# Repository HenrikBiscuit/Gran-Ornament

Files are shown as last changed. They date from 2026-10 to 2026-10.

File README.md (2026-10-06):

# Gran Ornament

A small, rechargeable, two-sided LED Christmas ornament. Twenty warm-white LEDs in seven channels (three rows per side and a shared star) play slow and calm light: steady high or low, a slow breath, or a flickering candle. One button turns it on, it fades in and out, switches itself off after four hours, and sleeps quietly between Christmases.

Made by hand in small batches in Denmark. This repository is the open build log: hardware, firmware, and the notes behind the decisions.

> **Status:** 🛠 Prototyping. First batch of Rev 1 boards ordered. Firmware runs on a dev board: four light modes, button, Standby, auto-off, battery compensation and low-battery cutoff. Nothing here is production-ready yet.

<!-- Add a photo here once you have one: ![Prototype](docs/images/prototype-v0.1.jpg) -->

## Using it

| Do this | What happens |
|---|---|
| Press the button | It fades in, in the mode it had last time (high if the battery has been disconnected) |
| Short press | Next mode: high → low → breathe → candle |
| Hold for 1.5 s | It fades out and switches off |
| Leave it on | It fades out and switches off by itself after 4 hours |
| Battery runs low | It fades out, pulses softly three times ("charge me") and switches off |
| Charge | USB-C |

The brightness stays the same while the battery drains, down to the 3.6 V cutoff.

## What's in here

| Folder | Contents |
|---|---|
| [`hardware/`](hardware/) | KiCad project, datasheet links, fabrication outputs (Gerbers, BOM, CPL). Each ordered revision is a [Release](../../releases), e.g. [`hw-v1`](../../releases/tag/hw-v1) |
| [`firmware/`](firmware/) | STM32G030 firmware. Runs on the dev board for now. How to build, test and lint: [`firmware/README.md`](firmware/README.md) |
| [`firmware/tests/`](firmware/tests/) | Host-side GoogleTest tests for the firmware logic, run in CI and by the pre-push gate |
| [`docs/`](docs/) | Design decisions, power budget, pinout, bring-up notes, images |
| `production/` | Programming and test process for each batch (not created yet) |
| [`CHANGELOG.md`](CHANGELOG.md) | What changed, per hardware and firmware version |

## Key parts (current choices)

| Function | Part | Notes |
|---|---|---|
| MCU | STM32G030F6P6 | Cortex-M0+, 64 MHz, 32 KB flash, 8 KB RAM, TSSOP-20 |
| LEDs | 20 × XL-1608WWC-06 | Warm white, 1608 metric (0603 imperial) |
| Charger | MCP73831 (SOT-23-5) | Linear single-cell Li-ion/LiPo charger, 4.20 V variant, 100 mA, USB-C input |
| Protection | DW01A + FS8205A | Over-discharge, over-charge and over-current protection on the board |
| Regulator | TPS7A0233 | 3.3 V LDO, ~25 nA quiescent current |
| Button | Alps SKRTLAE010 | Side-push SMD tact switch |
| Battery | Single-cell LiPo, 250 mAh planned | Cell size *TBD* (DD-002) |

Full design rationale: [`docs/design-decisions.md`](docs/design-decisions.md)

## Design goals

1. **Works next Christmas.** Every choice favours longevity: deep sleep, over-discharge protection, a battery that survives 11 months in a box.
2. **Calm light.** Gamma-corrected, high-resolution, flicker-free PWM. Nothing jumpy, nothing "disco".
3. **Safe to hang where children and pets are.** LiPo safety and robustness are requirements.
4. **Buildable by one or two people** in batches of about 150.

## Roadmap

- [x] Initial KiCad schematic
- [x] Dev board bring-up: PWM on all 7 channels, button, Standby and wake
- [x] Light modes: high, low, breathe, candle
- [x] Battery measurement, brightness compensation and low-battery cutoff (DD-011)
- [x] Fade in and out when switching on and off
- [x] PCB layout and fabrication files (Rev 1)
- [x] First batch of Rev 1 boards ordered
- [ ] Measure Standby current on the dev board
- [ ] Gamma-corrected brightness (smooth fades at the dim end)
- [ ] Stay off when a battery is first connected (saves ~100 mAh, see the power budget)
- [ ] VDD via VREFINT (battery reading stays accurate below ~3.4 V)
- [ ] First prototype boards (Rev 1) built and brought up
- [ ] Power budget measured against calculated
- [ ] Production test jig
- [ ] Compliance groundwork (CE, GPSR, Battery Regulation)

Open tasks are tracked in [Issues](../../issues).

## Licence

Gran Ornament is **source-available for non-commercial use**. You're welcome to build one for yourself, as a gift, or with a school or makerspace, and to share improvements.

**Selling it requires permission.** That covers selling assembled ornaments, kits, or boards made from these files. Get in touch at *henrik@smitt.dk* and we'll work something out.

| What | Licence |
|---|---|
| Hardware (`hardware/`), documentation and images (`docs/`) | [CC BY-NC-SA 4.0](LICENSE-CC-BY-NC-SA) |
| Firmware (`firmware/`) | [PolyForm Noncommercial 1.0.0](LICENSE) |

The name "Gran Ornament" and any logo are not covered by these licences. Please don't use them for your own builds.

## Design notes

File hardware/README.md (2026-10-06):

# Hardware

## Layout

| Path | What goes here |
|---|---|
| `kicad/` | The KiCad project (`.kicad_pro`, `.kicad_sch`, `.kicad_pcb`) plus project-local symbol and footprint libraries |
| `kicad/lib/` | Custom symbols (`.kicad_sym`) and footprints (`.pretty/`) used by this project only |
| `fabrication/<rev>/` | Exported Gerbers, drill files, BOM and CPL for each board revision sent to the assembler |
| `datasheets/` | Links to the datasheets of every part on the board |

## Revisions

| Rev | Date | Status | Notes |
|---|---|---|---|
| Rev 1 | 2026-10 | First batch ordered ([`fabrication/Rev1/`](fabrication/Rev1/)) | First design. JLCPCB assembly |

Each revision that is sent to fabrication gets a Git tag (`hw-v1`, `hw-v2`, ...) and a
GitHub Release with the fabrication zip attached, so it is always possible to see exactly
what was built.

## Viewing without KiCad

A PDF export of the schematic lives in `docs/schematic-revX.pdf` (File → Plot in the
schematic editor). Re-export it whenever the schematic changes meaningfully, so visitors
can follow along without installing KiCad.

## Before a design leaves the house

- [ ] ERC clean (or every remaining warning explained in a comment)
- [ ] DRC clean against the assembler's design rules
- [ ] Every part has an LCSC/manufacturer part number field
- [ ] BOM and CPL exported and spot-checked for rotation
- [ ] Title block: revision and date updated, no private address
- [ ] Schematic PDF exported to `docs/`
- [ ] Tagged `hw-vX` and fabrication zip attached to a Release

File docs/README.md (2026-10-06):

# Documentation

| File | What it is |
|---|---|
| [`design-decisions.md`](design-decisions.md) | Why each important choice was made. Append, never rewrite history. |
| [`power-budget.md`](power-budget.md) | Run time per charge and storage over a year, calculated and measured |
| [`pinout.md`](pinout.md) | MCU pin assignment, shared by schematic and firmware |
| [`bring-up/`](bring-up/) | Dated lab notes from the bench |
| `images/` | Photos and screenshots (resize to ~1600 px wide before committing) |
| `schematic-revX.pdf` | Schematic export for people without KiCad (not exported yet) |

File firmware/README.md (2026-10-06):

# Firmware

Target: **STM32G030F6P6** (Cortex-M0+, 32 KB flash, 8 KB RAM).
Toolchain: VS Code with the STM32Cube extension (CMake, GCC). CubeMX HAL, kept small and readable.

## Layout

| Path | What it is |
|---|---|
| `devboard/` | VS code project for the dev board. Experiments, bring-up tests, pattern tuning. |
| `ornament/` | VS Code project for the real ornament board (created once rev A exists). |
| `tests/` | Host-side GoogleTest tests for the hardware-independent code in `devboard/Gran_Ornament/App/Inc`. |

## Application code (`devboard/Gran_Ornament/App`)

CubeMX owns `Core/`. Our code lives in `App/` and starts at `app_run()`, called from `main.c`.
Logic that doesn't touch the hardware is kept in headers without HAL, so it can be tested on a PC.

| File | What it does | Host-tested |
|---|---|---|
| `app.cpp` | Main loop: button, modes, fades, battery, switch-off. Sleeps (`__WFI`) between 1 ms ticks | – |
| `modes.hpp` | The light modes (high, low, breathe, candle) and how the mode is stored | yes |
| `candle.hpp` | Candle flicker from Perlin-style noise | yes |
| `fade.hpp` | Fade in/out and the "charge me" pulses | yes |
| `battery.hpp` | Battery voltage, brightness compensation, low-battery cutoff (DD-011) | yes |
| `battery.cpp` | ADC reading of `VBAT_SENSE` | – |
| `button.hpp` | Debounce, short and long press | yes |
| `auto_off.hpp` | 4 h auto-off timer | yes |
| `pwm.hpp` | Brightness in permille to timer compare value | yes |
| `power.hpp`, `power.cpp` | Standby, wake-up and the backup register (DD-010) | – |

## Checks

Every push is checked the same way locally and in CI
([`.github/workflows/firmware.yml`](../.github/workflows/firmware.yml)):

1. **Build** the dev-board firmware (`cmake --preset Release`).
2. **Lint** with [`tools/lint.ps1`](../tools/lint.ps1):
   - `clang-format` checks the layout of our own code (`devboard/*/App/**`, `tests/*.cpp`)
     against [`.clang-format`](../.clang-format).
   - `clang-tidy` runs the bug-finding checks in [`.clang-tidy`](../.clang-tidy) on the
     firmware `App/` sources. It uses the firmware's `compile_commands.json` and the ARM GCC
     headers, so it needs the configure step above.
   - CubeMX-generated `Core/` and vendor `Drivers/` are never formatted or linted, so
     regenerating from the `.ioc` stays clean.
3. **Test**: build and run the host tests with CTest. On Windows the MSYS2 compiler folder
   (`C:\msys64\ucrt64\bin`) must be on `PATH`, or the test build fails without an error message.

Run all three locally with the pre-push gate:

```powershell
powershell -NoProfile -ExecutionPolicy Bypass -File tools/pre-push.ps1
```

To run it automatically on every `git push`, enable the repo's hooks once per clone:

```bash
git config core.hooksPath .githooks
```

To fix formatting, run `tools/lint.ps1 -Fix`, or turn on format-on-save in an editor that
uses clangd. Requires `clang-format` (LLVM 23, same major version as CI), `clang-tidy`, and
`arm-none-eabi-gcc` on `PATH`.

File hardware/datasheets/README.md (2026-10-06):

# Datasheets

Datasheets are linked rather than committed. Most manufacturers do not permit
redistribution, and links keep the repository small.

| Ref | Part | Manufacturer | LCSC | Datasheet |
|---|---|---|---|---|
| U1 | STM32G030F6P6 | STMicroelectronics | C529330 | [DS12991](https://www.st.com/resource/en/datasheet/stm32g030f6.pdf) |
| U2 | MCP73831-2-OT | Microchip | C424093 | [LCSC](https://www.lcsc.com/product-detail/C424093.html) |
| U3 | DW01A | – | C351410 | [LCSC](https://www.lcsc.com/product-detail/C351410.html) |
| U4 | FS8205A | Fortune | C2830320 | [LCSC](https://www.lcsc.com/product-detail/C2830320.html) |
| U5 | TPS7A0233PDBVR | Texas Instruments | C2887324 | [LCSC](https://www.lcsc.com/product-detail/C2887324.html) |
| D2, D4–D22 | XL-1608WWC-06 | XINGLIGHT | C965810 | [LCSC](https://www.lcsc.com/product-detail/C965810.html) |
| KEY1 | SKRTLAE010 | Alps Alpine | C110293 | [LCSC](https://www.lcsc.com/product-detail/C110293.html) |

Passives, connectors and the other LEDs: see the BOM in [`../fabrication/Rev1/`](../fabrication/Rev1/).

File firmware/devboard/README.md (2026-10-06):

# Dev board firmware

**Board:** WeAct STM32G030F6P6

## Bring-up checklist

Each step is a small, committed milestone. Tick it off and note results in
[`../../docs/bring-up/`](../../docs/bring-up/).

- [x] Blink an LED (toolchain + flashing works)
- [x] PWM on all 7 LED channels, 12 bit at ~3.9 kHz (DD-007)
- [x] Button: debounce, short press = next mode, long press = off (DD-009)
- [x] Standby and wake on the button via WKUP1 (DD-010)
- [x] Light modes: high, low, breathe, candle
- [x] Battery measurement on PA1, brightness compensation, 3.6 V cutoff (DD-011)
- [x] Fade in and out when switching on and off, "charge me" pulses
- [ ] 4-hour auto-off tested on the bench with a shortened timer (host-tested so far)
- [ ] Measure Standby current (ST-LINK disconnected, divider in place)
- [ ] Gamma-corrected fades: smooth at the very lowest levels, no steps visible
- [ ] Read VDD via VREFINT

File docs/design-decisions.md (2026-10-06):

# Design decisions

### DD-001 · MCU: STM32G030F6P6
**Date:** 2026-09
**Decision:** STM32G030F6P6 in TSSOP-20.
**Why:** Cheap, widely stocked at PCBA assemblers, enough timer channels for 7 independent LED channels, Stop/Standby modes for long sleep, hand-probeable package.
**Watch out:** Several TSSOP-20 pads carry more than one GPIO (pad 1 PB7/PB8, pad 2 PB9/PC14, pad 15 PA8/PB0/PB1/PB2, pad 20 PB3–PB6). Only one GPIO per pad can be used, and CubeMX only lets you assign one.
**Revisit if:** More independent LED channels are needed than the timers on the free pads can give.

### DD-002 · Battery
**Date:** – 2026-09
**Decision:** Single-cell LiPo, 250 mAh planned. Protection is on the board (DW01A + FS8205A). Charged at 100 mA by the MCP73831 (10k on PROG), about 0.4 C. Firmware cutoff at 3.6 V (DD-011). *Cell size and supplier TBD.*

### DD-003 · LED drive: per-LED resistor, MCU pin sinks
**Date:** 2026-09
**Decision:** All anodes on VBAT, one series resistor per LED on the cathode side, each band's resistors joined at one MCU pin in open-drain mode. No MOSFETs. Released pin = off.
**Why:** Fewest parts, no LED current in sleep, and the measured band current (~10 mA for 4 LEDs at 4.2 V) is inside the pin limits.
**Watch out:** A released pin floats up to about VDD, so band pins rely on 5 V tolerance. The pins are only 5 V tolerant when not in analog mode, and a pull-down would light the LEDs faintly.
**Revisit if:** Band current needs to go above ~15 mA per pin.

### DD-004 · Tree layout: 3 rows per side and a shared star
**Date:** 2026-09-29
**Decision:** Each side has 3 rows of 4-3-2 LEDs (bottom to top), each on its own PWM channel. The two star LEDs (one per side) share one channel. 7 channels in total.
**Why:** The planned 8th channel (PB9/TIM17) shares a pad with PC14 and can't be tested on the devboard. A shared star costs little: the star rarely needs to differ between sides.
**Watch out:** Patterns can't move the star from side to side. The charge gauge still has 4 steps (three rows, then the star).
**Revisit if:** A pattern really needs independent stars.

### DD-005 · LED pins and timers
**Date:** 2026-09-29, pins reassigned 2026-10-01
**Decision:** F1 PA11 (TIM1_CH4), F2 PB6 (TIM1_CH3), F3 PB8 (TIM16_CH1), B1 PA4 (TIM14_CH1), B2 PA6 (TIM3_CH1), B3 PA7 (TIM3_CH2), star PB0 (TIM1_CH2N). Front is side 2 and back is side 1 in the schematic. All alternate function open drain, no pull, polarity Low (duty = on-time).
**Why:** The combination CubeMX accepts on separate pads. On 2026-10-01 the schematic moved the star to PB0, B1 to PA4 and F3 to PB8, and the firmware channel table followed.
**Watch out:** PB0 is a complementary output. It's started with HAL_TIMEx_PWMN_Start, and its polarity is set by OCNPolarity, not OCPolarity. It must be `TIM_OCNPOLARITY_LOW` (CubeMX: TIM1 → CH2N Polarity), otherwise the star runs inverted. B1 (4 LEDs, ~10 mA) is now on PA4, an FT_a pin, which has a higher output-low voltage than FT_f, so B1 may look slightly dimmer than F1. Check it on the first PCB. It was High at first and was fixed on 2026-10-01. TIM17 and PB9 are unused. No LSE crystal is possible, because PB9 shares pad 2 with PC14.
**Revisit if:** The PCB layout wants a different pin order.

### DD-006 · Pin safety for LED pads
**Date:** 2026-09-29
**Decision:** Band pins are never put in analog mode and never get a pull-down, including in sleep. Unused GPIOs on shared pads are left unassigned, so CubeMX's "free pins as analog" puts them in analog mode.
**Why:** The bench test with PB7 in analog mode next to a released PB8 showed no measurable leakage (under ~2 µA per LED, no glow).
**Watch out:** The multimeter can only resolve ~2 µA per LED. Confirm with the sleep current on the first PCB.
**Revisit if:** Sleep current on the PCB is higher than the power budget allows.

### DD-007 · Clock and PWM resolution
**Date:** 2026-09-29
**Decision:** SYSCLK 16 MHz from HSI, no PLL. All LED timers at prescaler 0, period 4095: 12 bit at ~3.9 kHz.
**Why:** Lower run current than 64 MHz, which matters next to ~10 mA of LED current. 3.9 kHz is high enough to avoid camera flicker.
**Watch out:** Battery compensation (DD-011) uses only ~49 % of the range at full battery, so the dimmest fades have fewer steps.
**Revisit if:** A slow fade near off shows visible steps. Then add dithering or go to 32 MHz for 13 bit.

### DD-008 · LED series resistor
**Date:** 2026-10
**Decision:** 470 Ω, in the Rev 1 BOM.
**Why:** Electrically safe (~2.3 mA per LED at 4.1 V, measured), and more light than 680 Ω. The compensation makes every mode look as bright as at 3.6 V, so the extra headroom matters.
**Watch out:** Compensation runs at ~49 % duty at full battery (DD-011), so the dimmest fades have fewer steps (DD-007).
**Revisit if:** The ornament looks too bright, or the dim end of the fades shows steps.

### DD-009 · Button: one press to wake, short to change mode, long to switch off
**Date:** 2026-09-29
**Decision:** The button on PA0 goes to GND, with the internal pull-up, so a press reads low. While on, the main loop polls it every ~1 ms (no EXTI). Debounce 20 ms. A short press moves to the next mode, and holding for 1.5 s switches off. The press that wakes the ornament is ignored until it is released.
**Why:** Only one button, so it has to do everything. Polling is simple and easy to test on a PC (`Button` class, host tests). Wake-up from Standby doesn't need EXTI, it uses the WKUP1 pin (DD-010). The long press fires while the button is still held, so you see the LEDs go off without letting go.
**Watch out:** The devboard uses a limit switch (NO to PA0, common to GND). Pressed, the pull-up draws ~80 µA; released, nothing.
**Revisit if:** The loop gets too busy to poll every few ms, or the modes need a double press.

### DD-010 · Off means Standby, mode kept in a backup register
**Date:** 2026-09-29
**Decision:** Switching on fades in over 1 s. Switching off (long press, the 4 h auto-off or a low battery) fades out over 1 s, waits for the button to be released, and enters Standby. PA0 is WKUP1 and wakes the MCU on a falling edge. The PWR pull-up keeps PA0 high in Standby. Waking is a reset, and the current mode is read back from TAMP backup register 0 (`0x4752'0000 | mode`, anything else means the default mode).
**Why:** Standby is the lowest-current mode on the G030 (sub-µA, to be measured). Every other GPIO goes Hi-Z, so the open-drain LED pins are released and the LEDs stay off with no pull-down on the pads (DD-006). The backup register survives Standby and NRST, so the ornament comes back in the same mode.
**Watch out:** The debugger drops when the MCU enters Standby: press the button (or connect under reset) to flash again. The mode is lost when the battery is disconnected. If the button is stuck pressed (e.g. squeezed in the box), the ornament wakes, stays on for 4 h, then waits forever for the release with the CPU running. Not handled yet.
**Revisit if:** Measured Standby current is higher than the power budget allows, or the ornament must stay off after the battery is first connected.

### DD-011 · Battery measurement and brightness compensation
**Date:** 2026-10-06
**Decision:** VBAT is measured on PA1 (ADC1_IN1, `VBAT_SENSE`) through a 1M/1M divider with 0.1 µF on the ADC side. Sampling time 160.5 cycles, calibrated at boot, read once a second. Every LED level is multiplied by a brightness scale so the LEDs look as bright at any battery voltage as at 3.6 V: scale = (3.6 V − 3.03 V) / (VBAT − 3.03 V), capped at 100 %. 3.03 V is the measured LED VF (2.70 V) plus the pin's low voltage (0.33 V). That gives ~49 % at 4.2 V, ~66 % at 3.9 V and 100 % at 3.6 V and below. Below 3.6 V for 5 readings in a row (~5 s), the ornament fades out, pulses three times to say "charge me" (`fade.hpp`) and switches off (`LowBattery`), leaving roughly 10–20 % of the cell for storage. Code: `battery.hpp` (HAL-free, host-tested) and `battery.cpp` (ADC).
**Why:** LED current follows the voltage left across the series resistor, so without compensation a full battery is roughly twice as bright as one at 3.6 V. The divider draws ~2 µA all the time. The cap supplies the charge the ADC takes when sampling, which a 1M divider alone can't.
**Watch out:** The ADC reads relative to VDD (3.3 V LDO). Below ~3.4 V VBAT the LDO drops out, VDD falls with the battery and the reading stops tracking it. That doesn't change the brightness (the scale is already 100 % there), and the 3.6 V cutoff sits above it, so neither needs VREFINT. Powered from the programmer with no battery (VBAT about 3.0 V through the Schottky, or 0 V if it feeds the 3.3 V rail), the board reads as a flat battery and switches off after ~5 s. Below 3.6 V the LEDs dim with the battery. The 3.03 V drop comes from a single LED measurement. Readings lag a voltage change by ~0.25 s (divider and cap). Each board needs a calibration factor (`kVbatCalPermille`): the hand-wired dev board read 3.5 % low (0.8 % from VDD = 3.326 V, the rest from the divider), found by where the cutoff trips in Low mode. Measure trip points in a dim mode: in High, ~30 mV is lost in the bench leads. A multimeter on PA1 loads the 500 kΩ divider output by ~5 % and can trip the cutoff.
**Revisit if:** The first PCB measures a different VF, the LEDs look too dim overall (raise the 3.6 V point), or a year in storage leaves the cell too low (raise the cutoff towards 3.8 V).

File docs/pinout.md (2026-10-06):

# Pinout — STM32G030F6P6 (TSSOP-20)

| Pin | Name | Function | Net | Notes |
|---|---|---|---|---|
| 1 | PB8 (PB7) | TIM16_CH1, AF open drain | LED_F3 | Front top row, 2 LEDs. FT_f. PB7 unassigned |
| 2 | PB9 / PC14 | – | – | Unused. Shares pad with PC14-OSC32_IN, no LSE crystal |
| 3 | PC15 | – | – | Unused |
| 4 | VDD/VDDA | Supply | +3V3 | From 3.3 V LDO |
| 5 | VSS/VSSA | Ground | GND | |
| 6 | PF2-NRST | Reset | NRST | Test pad for pogo jig |
| 7 | PA0 | GPIO input, pull-up | BUTTON | WKUP1: wakes from Standby on a falling edge, pull-up kept in Standby (DD-010). Side-push button to GND (limit switch on devboard) |
| 8 | PA1 | ADC1_IN1, analog | VBAT_SENSE | VBAT through a 1M/1M divider, 0.1 µF to GND. Read once a second (DD-011) |
| 9 | PA2 | – | – | Free. Candidate for charger STAT |
| 10 | PA3 | – | – | Free |
| 11 | PA4 | TIM14_CH1, AF open drain | LED_B1 | Back bottom row, 4 LEDs. FT_a |
| 12 | PA5 | – | – | Free. Candidate for divider switch |
| 13 | PA6 | TIM3_CH1, AF open drain | LED_B2 | Back middle row, 3 LEDs. FT_ea |
| 14 | PA7 | TIM3_CH2, AF open drain | LED_B3 | Back top row, 2 LEDs. FT_a |
| 15 | PB0 (PA8, PB1, PB2) | TIM1_CH2N, AF open drain | LED_STAR | Both star LEDs. Complementary output, polarity Low. Others unassigned |
| 16 | PA11 [PA9] | TIM1_CH4, AF open drain | LED_F1 | Front bottom row, 4 LEDs. FT_fa |
| 17 | PA12 [PA10] | – | – | Unused |
| 18 | PA13 | SWDIO | SWDIO | Test pad for pogo jig |
| 19 | PA14-BOOT0 | SWCLK | SWCLK | Test pad for pogo jig |
| 20 | PB6 (PB3, PB4, PB5) | TIM1_CH3, AF open drain | LED_F2 | Front middle row, 3 LEDs. Others unassigned |

Front = side 2, back = side 1 in the schematic. The schematic labels the LED nets by timer channel (e.g. `TIM14_CH1`).

Fixed requirements: SWDIO + SWCLK + NRST + VDD + GND brought to test pads for the pogo-pin jig.
LED pads: never analog, never a pull-down (see DD-006).

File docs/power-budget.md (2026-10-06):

# Power budget

All numbers in one place. "Calc" is from datasheets, "Meas" is from the bench.

## Assumptions

| Item | Value | Source |
|---|---|---|
| Battery capacity | 250 mAh (planned) | DD-002 |
| Usable capacity (4.2 V → cutoff) | ~85 % of rated | Typical LiPo, to be confirmed |
| LED current at full brightness | ~2.3 mA per LED at 4.1 V (470 Ω), scaled to its 3.6 V level by compensation | Bring-up 2026-09-29, DD-011 |
| MCU run current | *TBD* mA | DS12991, run mode tables |
| Regulator quiescent current | ~0.025 µA typ | TPS7A02 datasheet (to confirm) |
| Charger reverse leakage (no input) | ~0.15 µA typ, ~2 µA max | MCP73831 datasheet (to confirm) |
| Protection IC (DW01A) | ~3 µA typ, ~6 µA max | DW01A datasheet (to confirm) |
| VBAT divider (1M/1M) | ~2 µA | VBAT / 2 MΩ |
| Low-battery cutoff | 3.6 V | DD-011 |

## Run time per charge

| Pattern | Avg duty | Avg LED current | MCU + reg. | Total | Hours per charge | Meas |
|---|---|---|---|---|---|---|
| High | – | – | – | – | – | – |
| Low | – | – | – | – | – | – |
| Breathe | – | – | – | – | – | – |
| Candle | – | – | – | – | – | – |

Hours per charge = usable capacity (mAh) ÷ total average current (mA)

## Storage (11 months in a box)

| Source | Current | Over 12 months |
|---|---|---|
Calc, typical (worst case in brackets). Every 1 µA drawn all the time costs 8.76 mAh a year.

| Source | Current | Over 12 months |
|---|---|---|
| MCU in Standby | ~0.3 µA (~1 µA) | ~3 mAh (~9 mAh) |
| Regulator quiescent | ~0.025 µA | ~0.2 mAh |
| Charger reverse leakage | ~0.15 µA (~2 µA) | ~1 mAh (~18 mAh) |
| Protection IC (DW01A) | ~3 µA (~6 µA) | ~26 mAh (~53 mAh) |
| VBAT divider | ~2 µA | ~18 mAh |
| LiPo self-discharge | ~2–3 %/month (typical, confirm with cell supplier) | ~60–90 mAh of 250 mAh |
| **Total** | ~5.5 µA (~11 µA) + self-discharge | **~110–140 mAh (~180 mAh)** |

At the 3.6 V cutoff roughly 25–50 mAh (10–20 %) is left, less than a year of storage needs. A 3.8 V cutoff
(~50 %) would cover the typical case. Biggest levers: a lower-current protection IC, a switched divider,
and confirming the cell's real self-discharge (some datasheets already include the protection IC in it).

**Watch out:** connecting the battery boots the ornament into its mode, and it stays on until a long press or
the 4 h auto-off. That first run costs up to ~100 mAh. Not handled yet.

Target: a unit stored at ~50–60 % charge in January still turns on next December.

## How to measure

- Run current: multimeter in series with the battery, average over a full pattern cycle.
- Sleep current: µA range, or a tool like a Nordic PPK2 / µCurrent. Disconnect the debugger first.

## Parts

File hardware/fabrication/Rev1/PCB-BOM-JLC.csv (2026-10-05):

Comment | Designator | Footprint | LCSC Part #
4.7uF | C1,C2 | C_0603_1608Metric | C19666
100nF | C3,C6,C7,C8 | C_0603_1608Metric | C1591
1uF | C4,C5 | C_0603_1608Metric | C15849
LED | D1 | D_0603_1608Metric | C2286
LED | D2,D4,D5,D6,D7,D8,D9,D10,D11,D12,D13,D14,D15,D16,D17,D18,D19,D20,D21,D22 | D_0603_1608Metric | C965810
D_Schottky | D3 | D_SOD-123 | C8598
USB_C_Receptacle_PowerOnly_6P | J1 | USB_C_Receptacle_GCT_USB4125-xx-x-0190_6P_TopMnt_Horizontal | C456012
Conn_01x05_Socket | J2 | HDR-SMD_5P-P2.54-H-M-W12.8-N | C46061678
Conn_01x02 | J3 | Molex_PicoBlade_53261-0271_1x02-1MP_P1.25mm_Horizontal | C177225
SKRTLAE010 | KEY1 | KEY-SMD_SKRTLAE010 | C110293
5.1k | R1,R2 | R_0603_1608Metric | C23186
10k | R3 | R_0603_1608Metric | C25804
1k | R4,R6 | R_0603_1608Metric | C21190
100 | R5 | R_0603_1608Metric | C22775
470 | R7,R8,R9,R10,R11,R12,R13,R14,R15,R16,R17,R18,R19,R20,R21,R22,R23,R24,R25,R26 | R_0603_1608Metric | C23179
1M | R27,R28 | R_0603_1608Metric | C22935
33 | R29 | R_0603_1608Metric | C23140
STM32G030F6Px | U1 | TSSOP-20_4.4x6.5mm_P0.65mm | C529330
MCP73831-2-OT | U2 | SOT-23-5 | C424093
DW01A | U3 | SOT-23-6 | C351410
FS8205A_C2830320 | U4 | SOT-23-6_L2.9-W1.6-P0.95-LS2.8-BR | C2830320
TPS7A0233PDBVR | U5 | SOT-23-5_L2.9-W1.6-P0.95-LS2.8-BR | C2887324

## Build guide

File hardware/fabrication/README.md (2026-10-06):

# Fabrication outputs

One folder per board revision, exported from KiCad for JLCPCB, for example:

```
fabrication/
└── Rev1/
    ├── PCB-*.gbr, PCB-*.drl      Gerber and drill files
    ├── PCB-job.gbrjob            Gerber job file
    ├── PCB-BOM-JLC.csv           Bill of materials in JLC's format (LCSC part numbers)
    ├── PCB-CPL-JLC.csv           Component placement (pick-and-place) in JLC's format
    ├── PCB-top.pos, -bottom.pos  KiCad placement files
    └── Rev1.zip                  Everything above, as uploaded to JLC
```

The same zip is attached to the matching GitHub Release (`hw-v1`).

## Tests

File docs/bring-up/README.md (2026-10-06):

# Bring-up log

Dated lab notes from the bench, newest at the bottom.

## 2026-09-24 · First blink

**Goal:** Program the board and blink LEDs

**Setup:** board, firmware commit, instruments

**What happened:** Time will tell

**Next:** Setting up git, then getting to it

## 2026-09-25 · First blink

**Goal:** Program the board and blink LEDs

**Setup:** board, firmware commit, instruments

**What happened:** The board blinked

**Next:** Implementing CI and Googletest

## 2026-09-25 · CI and Googletest

**Goal:** Have Github actions build project on multiple platforms and report any failures 

**Setup:** Github

**What happened:** Github was setup according to goals, and tested with fail cases

**Next:** Implementing PWM

## 2026-09-28 · PWM implementation

**Goal:** Have a dimable LED from A PWM signal

**Setup:** board, firmware commit, instruments

**What happened:** TIM3_CH1 was setup on pin PA6 (previously used for testing the LED), and is able to walk through a full duty cycle using internal timers (0-100% brigthness)

**Next:** Write useable function and setup tests for it

## 2026-09-29 · LED current and pin checks

**Goal:** Measure the real LED current on one band, and check that a released pin doesn't leak current through the LEDs

**Setup:** devboard, 4-LED test string (470 Ω per LED, anodes on a LiPo, cathodes sinking into PA6), multimeter

**What happened:** At VBAT 4.13 V with the pin held low: VF 2.70 V, 1.10 V across the resistor (2.34 mA per LED), 0.33 V on the pin at ~9.4 mA total. That works out to ~10 mA for a 4-LED band at 4.2 V, well inside the pin limits. A released pin floats up to 2.9–3.3 V. PB8 was tested with its shared-pad spare PB7 left in analog: the pad sits at VDD (3.32 V), the voltage across a resistor reads 0.000 V (under ~2 µA per LED) and there is no glow. Only one resistor has been measured so far.

**Next:** Drive every band pin from its own timer

## 2026-09-29 · All PWM channels

**Goal:** Drive every LED band from its own timer channel

**Setup:** devboard, 4-LED test string moved from pin to pin, firmware commit, multimeter

**What happened:** SYSCLK lowered to 16 MHz, all timers at period 4095 (12 bit, ~3.9 kHz), pins as alternate function open drain with polarity Low. A bench test steps through 0/25/50/100 % and then fades. PA11, PB6, PB0 (TIM1_CH2N), PB8, PA6, PA7 and PA4 all behave correctly, with no flash at reset. PB9/TIM17 could not be tested because the devboard's C14 header isn't connected to the chip (there is a 32.768 kHz crystal on PC14/PC15). PB9 is dropped, and the two star LEDs now share PA4.

**Next:** Button on PA0 (limit switch wired, NO)

## 2026-09-30 · Button wake and mode change

**Goal:** Wake from Standby with the button, change mode with a short press, switch off with a long press

**Setup:** devboard, limit switch (NO to PA0, common to GND), 4-LED test string, firmware commit

**What happened:** PA0 changed to input with pull-up (the switch goes to GND). Three placeholder modes: steady, breathe, dim. Short press = next mode, hold 1.5 s = off (Standby), press = wake in the same mode. Tried on the board and it works as expected. Host tests for the button and modes pass.

**Next:** Measure Standby current with the ST-Link unplugged. Later: handle a button that is stuck pressed (DD-010).

## 2026-10-01 · Light modes and F3 polarity

**Goal:** Replace the placeholder modes with real ones

**Setup:** devboard, limit switch on PA0, 4-LED test string, firmware commit

**What happened:** Four modes: high, low, breathe (16 s per breath) and candle (every channel flickers as its own flame). F3 (PB0, TIM1_CH2N) had CH2N Polarity High in CubeMX. Changed it to Low, and after some troubleshooting F3 now works like the other channels. Host tests for the modes and the candle pass.

**Next:** Measure Standby current with the ST-Link unplugged.

## 2026-10-06 · Battery measurement and cutoff

**Goal:** Read the battery voltage, keep brightness constant as it drains, and switch off before the cell runs flat
**Setup:** devboard, 1M/1M divider with 0.1 µF on PA1 (taped and heatshrunk, not probeable), bench supply on VBAT, multimeter, firmware commit
**What happened:** ADC1_IN1 at 160.5 cycles, calibrated at boot. A blink-rate test (faster at higher VBAT) showed the reading follows the supply. Brightness compensation holds every mode at its 3.6 V brightness, and the cutoff fades out, pulses three times and goes to Standby. Uncalibrated, the 3.6 V cutoff tripped at 3.76 V in High and 3.73 V in Low: ~30 mV is lost in the bench leads under load, ~0.8 % comes from VDD (3.326 V), the rest from the divider. A multimeter on PA1 (500 kΩ source) pulled it down ~5 % and tripped the cutoff while measuring. With a +3.5 % calibration the cutoff trips at 3.63 V in High and 3.61 V in Low.
**Next:** Check the divider and calibration on the first PCB (1 % resistors). Measure Standby current with the divider in place.

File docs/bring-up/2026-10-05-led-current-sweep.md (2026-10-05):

# 2026-10-05 · LED current vs. battery voltage

Results from the devboard bench test. Lab notes are in [README.md](README.md), raw data in [2026-10-05-led-current-sweep.csv](2026-10-05-led-current-sweep.csv).

## Setup

| | |
|---|---|
| Supply | Bench PSU in place of the LiPo, 4.2 V → 3.0 V in 0.1 V steps |
| MCU supply | MCP1700 LDO, ST-Link 3.3 V wire removed |
| LEDs | 10, wired as on the ornament: rows of 4, 3 and 2, plus 1 star LED |
| Series resistor | 470 Ω per LED |
| Band pins | Held low continuously (no PWM) |
| PSU resolution | 1 mA |
| Room temperature | 22 °C |

## PSU readings (mA)

| VBAT (V) | All off | Row 1 (4 LEDs) | Row 2 (3) | Row 3 (2) | Star (1) | All on |
|---:|---:|---:|---:|---:|---:|---:|
| 4.2 | 1 | 10 | 9 | 6 | 4 | 26 |
| 4.1 | 1 | 10 | 8 | 6 | 3 | 24 |
| 4.0 | 1 | 9 | 8 | 5 | 3 | 22 |
| 3.9 | 1 | 9 | 7 | 5 | 3 | 21 |
| 3.8 | 1 | 8 | 6 | 5 | 3 | 20 |
| 3.7 | 1 | 8 | 6 | 4 | 3 | 18 |
| 3.6 | 1 | 7 | 5 | 4 | 3 | 17 |
| 3.5 | 1 | 6 | 5 | 4 | 2 | 15 |
| 3.4 | 1 | 5 | 4 | 3 | 2 | 13 |
| 3.3 | 1 | 5 | 4 | 4 | 3 | 12 |
| 3.2 | 1 | 5 | 4 | 3 | 2 | 11 |
| 3.1 | 1 | 4 | 4 | 3 | 2 | 9 |
| 3.0 | 1 | 4 | 3 | 3 | 2 | 8 |

An all-LEDs re-check at 4.2 V at the end of the test read 26 mA again. The 3.3 V readings for row 3 and the star are 1 mA high, probably a misread; the all-on reading at 3.3 V is on the line.

## Current per LED and compensation

Measured = (all on − all off) ÷ 10. Fit: **I = (VBAT − 2.55 V) / 672 Ω**. Duty is what holds the brightness at the 3.5 V level: duty = (3.5 − 2.55) / (VBAT − 2.55), capped at 100 %.

| VBAT (V) | Measured (mA/LED) | Fit (mA/LED) | Compensation duty |
|---:|---:|---:|---:|
| 4.2 | 2.50 | 2.46 | 58 % |
| 4.1 | 2.30 | 2.31 | 61 % |
| 4.0 | 2.10 | 2.16 | 66 % |
| 3.9 | 2.00 | 2.01 | 70 % |
| 3.8 | 1.90 | 1.86 | 76 % |
| 3.7 | 1.70 | 1.71 | 83 % |
| 3.6 | 1.60 | 1.56 | 90 % |
| 3.5 | 1.40 | 1.41 | 100 % |
| 3.4 | 1.20 | 1.26 | 100 % |
| 3.3 | 1.10 | 1.12 | 100 % |
| 3.2 | 1.00 | 0.97 | 100 % |
| 3.1 | 0.80 | 0.82 | 100 % |
| 3.0 | 0.70 | 0.67 | 100 % |

## 470 Ω vs. 680 Ω

The full-to-floor ratio depends only on V0 = 2.55 V, so both resistors need ~58 % duty at 4.2 V. The 680 Ω values are estimated with the same ~200 Ω of LED and pin resistance.

| | 470 Ω (measured) | 680 Ω (estimated) |
|---|---:|---:|
| Per LED at 4.2 V | 2.46 mA | ~1.9 mA |
| Per LED at 3.5 V | 1.41 mA | ~1.1 mA |
| 4-LED row at 4.2 V | ~9 mA | ~7.5 mA |
| All ten LEDs at 4.2 V | ~25 mA | ~19 mA |
| Duty at 4.2 V for a 3.5 V floor | 58 % | 58 % |

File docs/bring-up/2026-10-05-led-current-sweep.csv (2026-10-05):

# R_ohm=470; psu_res_mA=1; date=2026-10-05; ldo=MCP1700; leds=bin unknown; temp_C=22; allon_recheck_4v2_mA=26; notes=
vbat_V | i_alloff_mA | i_row1_mA | i_row2_mA | i_row3_mA | i_star_mA | i_allon_mA | iled_row1_mA | iled_row2_mA | iled_row3_mA | iled_star_mA | vfvol_row1_V | vfvol_row2_V | vfvol_row3_V | vfvol_star_V | sumcheck_mA
4.2 | 1 | 10 | 9 | 6 | 4 | 26 | 2.250 | 2.667 | 2.500 | 3.000 | 3.143 | 2.947 | 3.025 | 2.790 | 0.00
4.1 | 1 | 10 | 8 | 6 | 3 | 24 | 2.250 | 2.333 | 2.500 | 2.000 | 3.042 | 3.003 | 2.925 | 3.160 | 0.00
4.0 | 1 | 9 | 8 | 5 | 3 | 22 | 2.000 | 2.333 | 2.000 | 2.000 | 3.060 | 2.903 | 3.060 | 3.060 | 0.00
3.9 | 1 | 9 | 7 | 5 | 3 | 21 | 2.000 | 2.000 | 2.000 | 2.000 | 2.960 | 2.960 | 2.960 | 2.960 | 0.00
3.8 | 1 | 8 | 6 | 5 | 3 | 20 | 1.750 | 1.667 | 2.000 | 2.000 | 2.978 | 3.017 | 2.860 | 2.860 | -1.00
3.7 | 1 | 8 | 6 | 4 | 3 | 18 | 1.750 | 1.667 | 1.500 | 2.000 | 2.878 | 2.917 | 2.995 | 2.760 | 0.00
3.6 | 1 | 7 | 5 | 4 | 3 | 17 | 1.500 | 1.333 | 1.500 | 2.000 | 2.895 | 2.973 | 2.895 | 2.660 | -1.00
3.5 | 1 | 6 | 5 | 4 | 2 | 15 | 1.250 | 1.333 | 1.500 | 1.000 | 2.913 | 2.873 | 2.795 | 3.030 | -1.00
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

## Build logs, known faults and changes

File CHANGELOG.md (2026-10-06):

# Changelog

Hardware and firmware are versioned separately.

## Unreleased
### Hardware
- Initial KiCad schematic: STM32G030F6P6, MCP73831 charger, 20 warm-white LEDs in two groups, side-push button.
- LED layout changed to 3 rows per side plus a shared star, 7 PWM channels (DD-004, DD-005).
- Global labels for the 7 LED timer channels and PROG_PWR.
- LED pins reassigned: star on PB0 (TIM1_CH2N), back bottom row on PA4 (TIM14_CH1), front top row on PB8 (TIM16_CH1) (DD-005).
- Rev 1 PCB layout. Power path: USB-C, MCP73831 charger (100 mA), DW01A + FS8205A protection, TPS7A0233 LDO. 470 Ω per LED, 1M/1M VBAT divider on PA1.
- Rev 1 fabrication files for JLCPCB (Gerbers, BOM, CPL) in `hardware/fabrication/Rev1/`. First batch ordered.
### Firmware
- Dev board bring-up started.
- PWM on all 7 LED channels (TIM1, TIM3, TIM14, TIM16), open drain, 12 bit at ~3.9 kHz.
- SYSCLK lowered to 16 MHz.
- Bench test in `app_run()`: fixed steps and a fade on every channel.
- Button on PA0 (to GND, pull-up): short press = next mode, hold 1.5 s = off, press = wake (DD-009).
- Off = Standby, woken by WKUP1 on PA0. The mode survives Standby in a backup register (DD-010).
- Three placeholder modes (steady, breathe, dim) replace the bench test. 4 h auto-off is active.
- Host tests for the button and the modes.
- Four modes replace the placeholders: high, low, breathe (now 16 s per breath, 8 s up and 8 s down) and candle.
- Candle mode: every channel flickers as its own flame, generated from Perlin-style noise (`candle.hpp`), with host tests.
- Fixed: F3 (PB0, TIM1_CH2N) ran inverted because its CH2N polarity was High. It is now Low (DD-005).
- Channel table follows the new LED pins: star on PB0, B1 on PA4, F3 on PB8.
- Battery measurement on PA1 (ADC1_IN1, `VBAT_SENSE`) through a 1M/1M divider, read once a second (`battery.hpp`, `battery.cpp`).
- Brightness compensation: every mode looks as bright as at 3.6 V, at any battery voltage (DD-011).
- Low-battery cutoff at 3.6 V: fade out, three soft "charge me" pulses, then Standby.
- Fade in at switch-on and fade out at switch-off, 1 s each (`fade.hpp`).
- Dev board battery calibration (+3.5 %), measured on the bench.
- Main loop sleeps (`__WFI`) until the next 1 ms tick instead of busy-waiting in `HAL_Delay`.
- Host tests for the battery maths, the cutoff and the fades.
### Tooling
- Lint with `clang-format` and `clang-tidy` (`tools/lint.ps1`). It runs in the pre-push gate and as a `lint` CI job, and covers `App/` and host test code only.
### Docs
- Repository structure, design decision log, power budget template.
- Pinout filled in.
- Design decisions DD-003 to DD-010.
- Bring-up log: LED current, pin leakage and PWM channel tests, button wake and mode change, light modes and the F3 polarity fix.
- DD-005 corrected: CH2N needs OCNPolarity Low.
- DD-011 battery measurement and compensation. DD-007, DD-008 and DD-010 updated to match.
- Power budget: storage drain calculated for a 250 mAh cell.
- Pinout: PA1 is VBAT_SENSE.
- Bring-up log: battery measurement and cutoff.
- All Markdown files brought up to date: README status, parts and roadmap, hardware revisions, datasheet list, firmware module overview, dev-board checklist. DD-002 and DD-008 decided. The bring-up log renders as Markdown again.

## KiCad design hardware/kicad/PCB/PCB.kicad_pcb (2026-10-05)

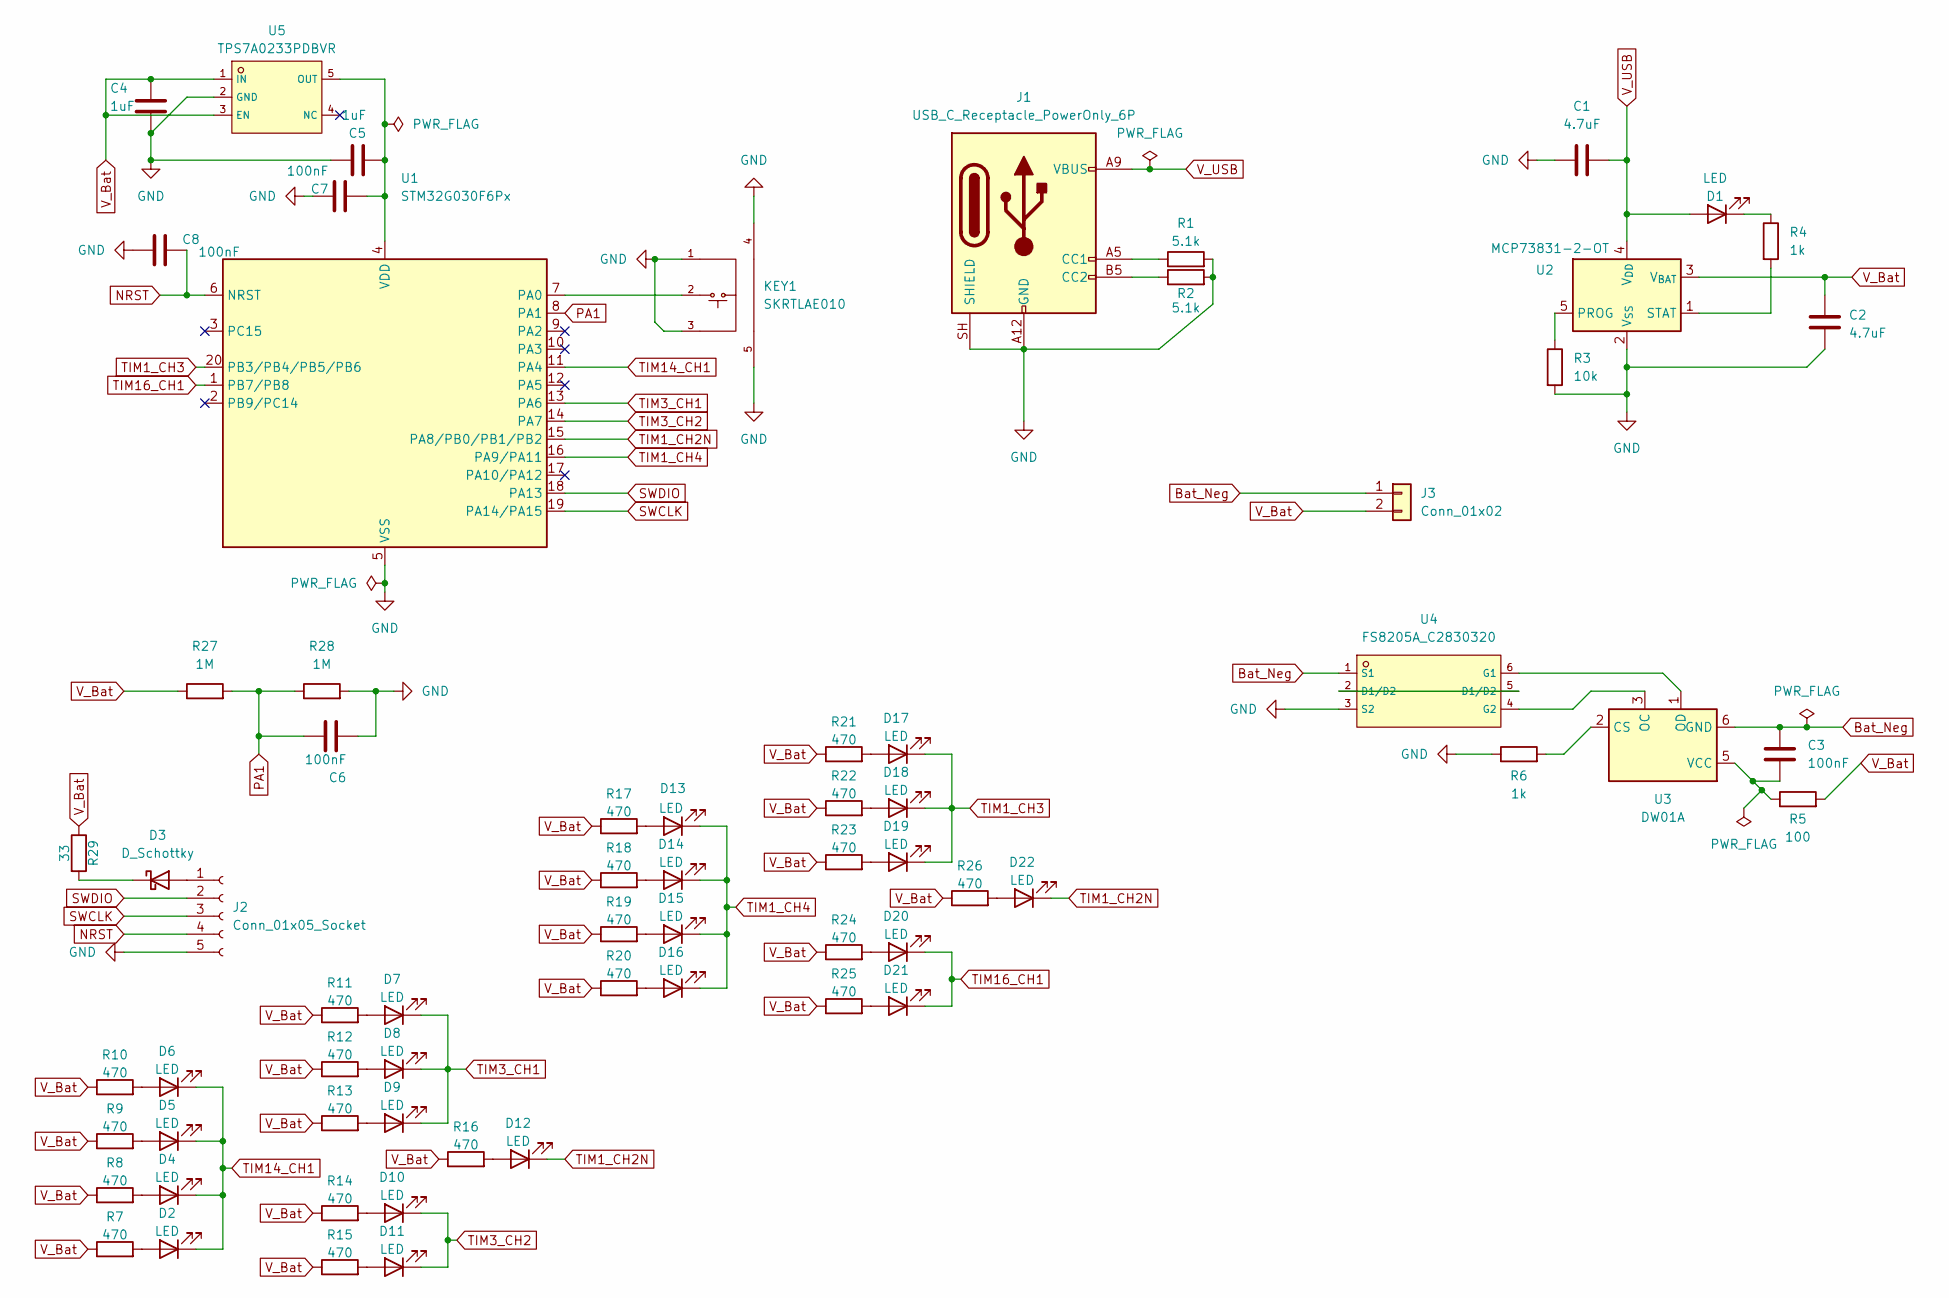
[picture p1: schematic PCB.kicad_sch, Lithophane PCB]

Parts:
C1, C2: 4.7uF; C_0603_1608Metric; LCSC C19666
C3, C6, C7, C8: 100nF; C_0603_1608Metric; LCSC C1591
C4, C5: 1uF; C_0603_1608Metric; LCSC C15849
D1: LED; D_0603_1608Metric; LCSC C2286
D2, D4, D5, D6, D7, D8, D9, D10, D11, D12, D13, D14, D15, D16, D17, D18, D19, D20, D21, D22: LED; D_0603_1608Metric; LCSC C965810
D3: D_Schottky; D_SOD-123; LCSC C8598
J1: USB_C_Receptacle_PowerOnly_6P; USB_C_Receptacle_GCT_USB4125-xx-x-0190_6P_TopMnt_Horizontal; LCSC C456012
J2: Conn_01x05_Socket; HDR-SMD_5P-P2.54-H-M-W12.8-N; LCSC C46061678
J3: Conn_01x02; Molex_PicoBlade_53261-0271_1x02-1MP_P1.25mm_Horizontal; LCSC C177225
KEY1: SKRTLAE010; KEY-SMD_SKRTLAE010; LCSC C110293
R1, R2: 5.1k; R_0603_1608Metric; LCSC C23186
R3: 10k; R_0603_1608Metric; LCSC C25804
R4, R6: 1k; R_0603_1608Metric; LCSC C21190
R5: 100; R_0603_1608Metric; LCSC C22775
R7, R8, R9, R10, R11, R12, R13, R14, R15, R16, R17, R18, R19, R20, R21, R22, R23, R24, R25, R26: 470; R_0603_1608Metric; LCSC C23179
R27, R28: 1M; R_0603_1608Metric; LCSC C22935
R29: 33; R_0603_1608Metric; LCSC C23140
U1: STM32G030F6Px; TSSOP-20_4.4x6.5mm_P0.65mm; LCSC C529330
U2: MCP73831-2-OT; SOT-23-5; LCSC C424093
U3: DW01A; SOT-23-6; LCSC C351410
U4: FS8205A_C2830320; SOT-23-6_L2.9-W1.6-P0.95-LS2.8-BR; LCSC C2830320
U5: TPS7A0233PDBVR; SOT-23-5_L2.9-W1.6-P0.95-LS2.8-BR; LCSC C2887324

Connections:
Bat_Neg: C3.1, J3.1, U3.6 (GND), U4.1 (S1)
GND: C1.1, C2.2, C4.2, C5.1, C6.2, C7.1, C8.2, J1.A12 (GND), J1.B12 (GND), J1.SH (SHIELD), J2.5, KEY1.1, KEY1.3, KEY1.4, KEY1.5, R1.2, R2.2, R3.2, R6.1, R28.2, U1.5 (VSS), U2.2 (V_{SS}), U4.3 (S2), U5.2 (GND)
NRST: C8.1, J2.4, U1.6 (NRST)
unnamed: D1.1 (K), R4.1
unnamed: D2.2 (A), R7.2
unnamed: D3.2 (A), J2.1
unnamed: D3.1 (K), R29.2
unnamed: D4.2 (A), R8.2
unnamed: D5.2 (A), R9.2
unnamed: D6.2 (A), R10.2
unnamed: D7.2 (A), R11.2
unnamed: D8.2 (A), R12.2
unnamed: D9.2 (A), R13.2
unnamed: D10.2 (A), R14.2
unnamed: D11.2 (A), R15.2
unnamed: D12.2 (A), R16.2
unnamed: D13.2 (A), R17.2
unnamed: D14.2 (A), R18.2
unnamed: D15.2 (A), R19.2
unnamed: D16.2 (A), R20.2
unnamed: D17.2 (A), R21.2
unnamed: D18.2 (A), R22.2
unnamed: D19.2 (A), R23.2
unnamed: D20.2 (A), R24.2
unnamed: D21.2 (A), R25.2
unnamed: D22.2 (A), R26.2
unnamed: J1.A5 (CC1), R1.1
unnamed: J1.B5 (CC2), R2.1
unnamed: KEY1.2, U1.7 (PA0)
unnamed: C5.2, C7.2, U1.4 (VDD), U5.5 (OUT)
unnamed: R3.1, U2.5 (PROG)
unnamed: R4.2, U2.1 (STAT)
unnamed: R6.2, U3.2 (CS)
unnamed: U3.3 (OC), U4.4 (G2)
unnamed: U3.1 (OD), U4.6 (G1)
unnamed: C3.2, R5.1, U3.5 (VCC)
unnamed: U4.2 (D1/D2), U4.5 (D1/D2)
PA1: C6.1, R27.2, R28.1, U1.8 (PA1)
SWCLK: J2.3, U1.19 (PA14/PA15)
SWDIO: J2.2, U1.18 (PA13)
TIM1_CH2N: D12.1 (K), D22.1 (K), U1.15 (PA8/PB0/PB1/PB2)
TIM1_CH3: D17.1 (K), D18.1 (K), D19.1 (K), U1.20 (PB3/PB4/PB5/PB6)
TIM1_CH4: D13.1 (K), D14.1 (K), D15.1 (K), D16.1 (K), U1.16 (PA9/PA11)
TIM3_CH1: D7.1 (K), D8.1 (K), D9.1 (K), U1.13 (PA6)
TIM3_CH2: D10.1 (K), D11.1 (K), U1.14 (PA7)
TIM14_CH1: D2.1 (K), D4.1 (K), D5.1 (K), D6.1 (K), U1.11 (PA4)
TIM16_CH1: D20.1 (K), D21.1 (K), U1.1 (PB7/PB8)
V_Bat: C2.1, C4.1, J3.2, R5.2, R7.1, R8.1, R9.1, R10.1, R11.1, R12.1, R13.1, R14.1, R15.1, R16.1, R17.1, R18.1, R19.1, R20.1, R21.1, R22.1, R23.1, R24.1, R25.1, R26.1, R27.1, R29.1, U2.3 (V_{BAT}), U5.1 (IN), U5.3 (EN)
V_USB: C1.2, D1.2 (A), J1.A9 (VBUS), J1.B9 (VBUS), U2.4 (V_{DD})

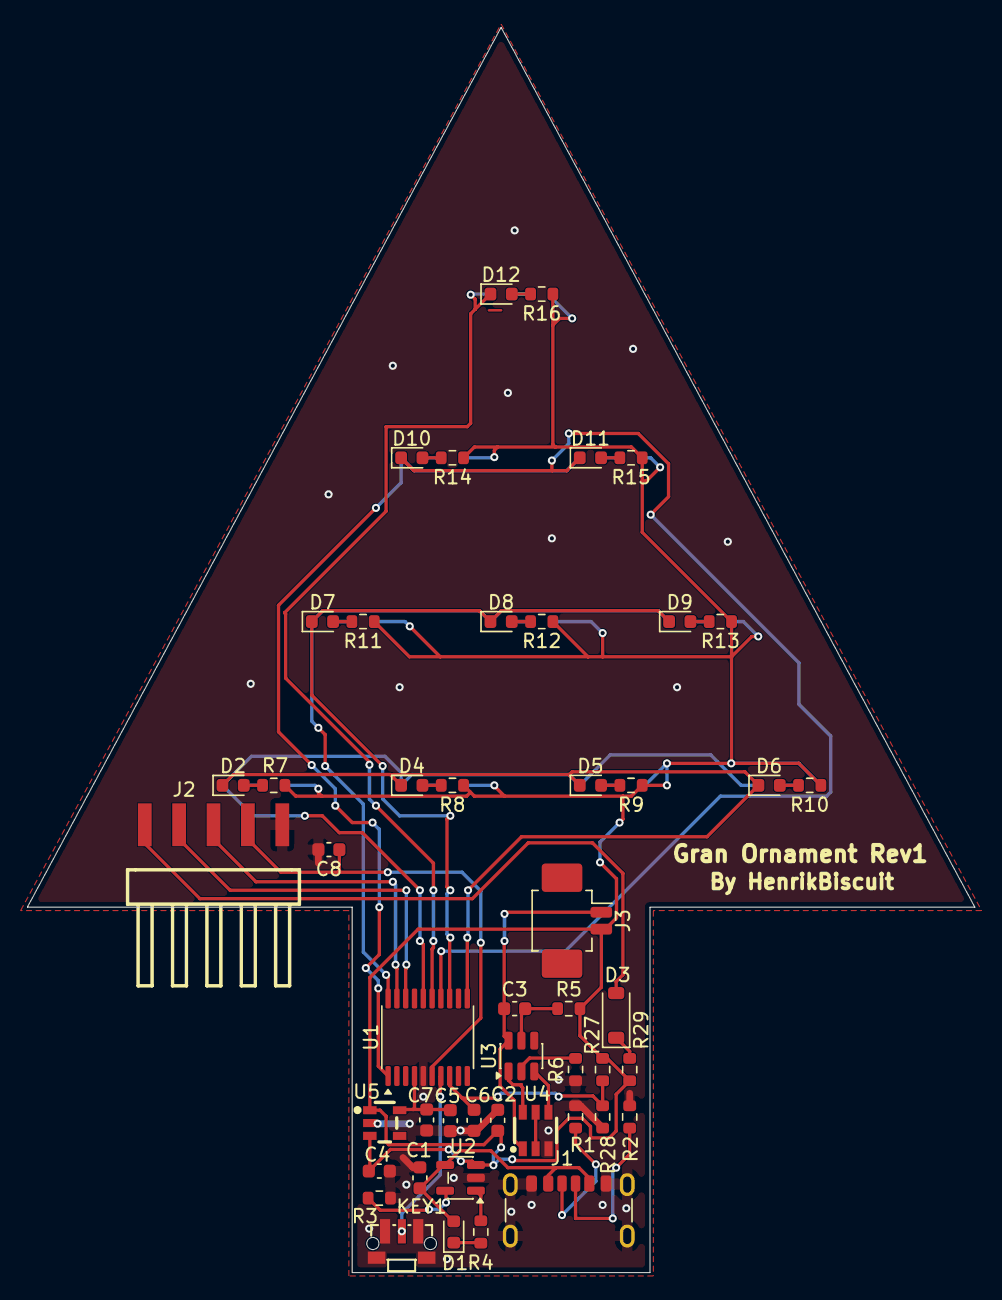
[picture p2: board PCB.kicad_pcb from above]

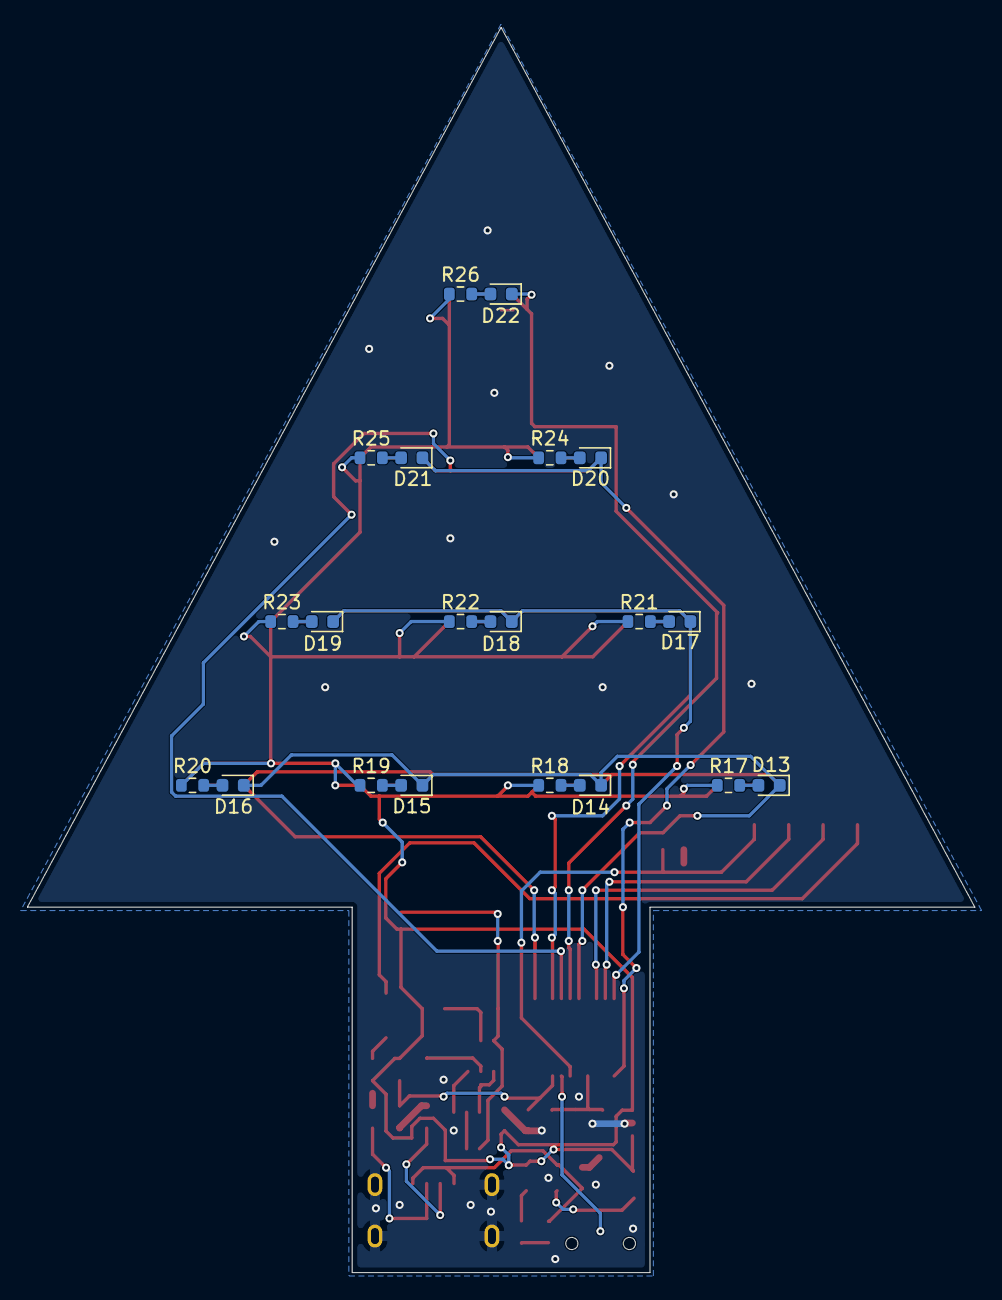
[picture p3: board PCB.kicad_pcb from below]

Board: 2 copper layers, 70.0 x 92.0 mm, 68 parts (20 on the bottom side), 49 nets.

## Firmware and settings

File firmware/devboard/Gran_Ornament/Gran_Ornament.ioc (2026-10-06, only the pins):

Mcu.UserName=STM32G030F6Px
PA0.GPIO_Label=BTN
PA0.Signal=GPIO_Input
PA1.GPIO_Label=VBAT_SENSE
PA1.Signal=ADC1_IN1
PA13.Signal=SYS_SWDIO
PA14-BOOT0.Signal=SYS_SWCLK
PA4.Signal=S_TIM14_CH1
PA6.Signal=S_TIM3_CH1
PA7.Signal=S_TIM3_CH2
PB0.Signal=TIM1_CH2N
PB6.Signal=S_TIM1_CH3
PB8.Signal=S_TIM16_CH1

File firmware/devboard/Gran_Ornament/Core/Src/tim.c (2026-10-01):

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
/* Includes ------------------------------------------------------------------*/
#include "tim.h"

TIM_HandleTypeDef htim1;
TIM_HandleTypeDef htim3;
TIM_HandleTypeDef htim14;
TIM_HandleTypeDef htim16;

/* TIM1 init function */
void MX_TIM1_Init(void)
{

  TIM_MasterConfigTypeDef sMasterConfig = {0};
  TIM_OC_InitTypeDef sConfigOC = {0};
  TIM_BreakDeadTimeConfigTypeDef sBreakDeadTimeConfig = {0};

  htim1.Instance = TIM1;
  htim1.Init.Prescaler = 0;
  htim1.Init.CounterMode = TIM_COUNTERMODE_UP;
  htim1.Init.Period = 4095;
  htim1.Init.ClockDivision = TIM_CLOCKDIVISION_DIV1;
  htim1.Init.RepetitionCounter = 0;
  htim1.Init.AutoReloadPreload = TIM_AUTORELOAD_PRELOAD_ENABLE;
  if (HAL_TIM_PWM_Init(&htim1) != HAL_OK)
  {
    Error_Handler();
  }
  sMasterConfig.MasterOutputTrigger = TIM_TRGO_RESET;
  sMasterConfig.MasterOutputTrigger2 = TIM_TRGO2_RESET;
  sMasterConfig.MasterSlaveMode = TIM_MASTERSLAVEMODE_DISABLE;
  if (HAL_TIMEx_MasterConfigSynchronization(&htim1, &sMasterConfig) != HAL_OK)
  {
    Error_Handler();
  }
  sConfigOC.OCMode = TIM_OCMODE_PWM1;
  sConfigOC.Pulse = 0;
  sConfigOC.OCPolarity = TIM_OCPOLARITY_HIGH;
  sConfigOC.OCNPolarity = TIM_OCNPOLARITY_LOW;
  sConfigOC.OCFastMode = TIM_OCFAST_DISABLE;
  sConfigOC.OCIdleState = TIM_OCIDLESTATE_RESET;
  sConfigOC.OCNIdleState = TIM_OCNIDLESTATE_RESET;
  if (HAL_TIM_PWM_ConfigChannel(&htim1, &sConfigOC, TIM_CHANNEL_2) != HAL_OK)
  {
    Error_Handler();
  }
  sConfigOC.OCPolarity = TIM_OCPOLARITY_LOW;
  sConfigOC.OCNPolarity = TIM_OCNPOLARITY_HIGH;
  if (HAL_TIM_PWM_ConfigChannel(&htim1, &sConfigOC, TIM_CHANNEL_3) != HAL_OK)
  {
    Error_Handler();
  }
  if (HAL_TIM_PWM_ConfigChannel(&htim1, &sConfigOC, TIM_CHANNEL_4) != HAL_OK)
  {
    Error_Handler();
  }
  sBreakDeadTimeConfig.OffStateRunMode = TIM_OSSR_DISABLE;
  sBreakDeadTimeConfig.OffStateIDLEMode = TIM_OSSI_DISABLE;
  sBreakDeadTimeConfig.LockLevel = TIM_LOCKLEVEL_OFF;
  sBreakDeadTimeConfig.DeadTime = 0;
  sBreakDeadTimeConfig.BreakState = TIM_BREAK_DISABLE;
  sBreakDeadTimeConfig.BreakPolarity = TIM_BREAKPOLARITY_HIGH;
  sBreakDeadTimeConfig.BreakFilter = 0;
  sBreakDeadTimeConfig.BreakAFMode = TIM_BREAK_AFMODE_INPUT;
  sBreakDeadTimeConfig.Break2State = TIM_BREAK2_DISABLE;
  sBreakDeadTimeConfig.Break2Polarity = TIM_BREAK2POLARITY_HIGH;
  sBreakDeadTimeConfig.Break2Filter = 0;
  sBreakDeadTimeConfig.Break2AFMode = TIM_BREAK_AFMODE_INPUT;
  sBreakDeadTimeConfig.AutomaticOutput = TIM_AUTOMATICOUTPUT_DISABLE;
  if (HAL_TIMEx_ConfigBreakDeadTime(&htim1, &sBreakDeadTimeConfig) != HAL_OK)
  {
    Error_Handler();
  }
  HAL_TIM_MspPostInit(&htim1);

}
/* TIM3 init function */
void MX_TIM3_Init(void)
{

  TIM_ClockConfigTypeDef sClockSourceConfig = {0};
  TIM_MasterConfigTypeDef sMasterConfig = {0};
  TIM_OC_InitTypeDef sConfigOC = {0};

  htim3.Instance = TIM3;
  htim3.Init.Prescaler = 0;
  htim3.Init.CounterMode = TIM_COUNTERMODE_UP;
  htim3.Init.Period = 4095;
  htim3.Init.ClockDivision = TIM_CLOCKDIVISION_DIV1;
  htim3.Init.AutoReloadPreload = TIM_AUTORELOAD_PRELOAD_ENABLE;
  if (HAL_TIM_Base_Init(&htim3) != HAL_OK)
  {
    Error_Handler();
  }
  sClockSourceConfig.ClockSource = TIM_CLOCKSOURCE_INTERNAL;
  if (HAL_TIM_ConfigClockSource(&htim3, &sClockSourceConfig) != HAL_OK)
  {
    Error_Handler();
  }
  if (HAL_TIM_PWM_Init(&htim3) != HAL_OK)
  {
    Error_Handler();
  }
  sMasterConfig.MasterOutputTrigger = TIM_TRGO_RESET;
  sMasterConfig.MasterSlaveMode = TIM_MASTERSLAVEMODE_DISABLE;
  if (HAL_TIMEx_MasterConfigSynchronization(&htim3, &sMasterConfig) != HAL_OK)
  {
    Error_Handler();
  }
  sConfigOC.OCMode = TIM_OCMODE_PWM1;
  sConfigOC.Pulse = 0;
  sConfigOC.OCPolarity = TIM_OCPOLARITY_LOW;
  sConfigOC.OCFastMode = TIM_OCFAST_DISABLE;
  if (HAL_TIM_PWM_ConfigChannel(&htim3, &sConfigOC, TIM_CHANNEL_1) != HAL_OK)
  {
    Error_Handler();
  }
  if (HAL_TIM_PWM_ConfigChannel(&htim3, &sConfigOC, TIM_CHANNEL_2) != HAL_OK)
  {
    Error_Handler();
  }
  HAL_TIM_MspPostInit(&htim3);

}
/* TIM14 init function */
void MX_TIM14_Init(void)
{

  TIM_OC_InitTypeDef sConfigOC = {0};

  htim14.Instance = TIM14;
  htim14.Init.Prescaler = 0;
  htim14.Init.CounterMode = TIM_COUNTERMODE_UP;
  htim14.Init.Period = 4095;
  htim14.Init.ClockDivision = TIM_CLOCKDIVISION_DIV1;
  htim14.Init.AutoReloadPreload = TIM_AUTORELOAD_PRELOAD_ENABLE;
  if (HAL_TIM_Base_Init(&htim14) != HAL_OK)
  {
    Error_Handler();
  }
  if (HAL_TIM_PWM_Init(&htim14) != HAL_OK)
  {
    Error_Handler();
  }
  sConfigOC.OCMode = TIM_OCMODE_PWM1;
  sConfigOC.Pulse = 0;
  sConfigOC.OCPolarity = TIM_OCPOLARITY_LOW;
  sConfigOC.OCFastMode = TIM_OCFAST_DISABLE;
  if (HAL_TIM_PWM_ConfigChannel(&htim14, &sConfigOC, TIM_CHANNEL_1) != HAL_OK)
  {
    Error_Handler();
  }
  HAL_TIM_MspPostInit(&htim14);

}
/* TIM16 init function */
void MX_TIM16_Init(void)
{

  TIM_OC_InitTypeDef sConfigOC = {0};
  TIM_BreakDeadTimeConfigTypeDef sBreakDeadTimeConfig = {0};

  htim16.Instance = TIM16;
  htim16.Init.Prescaler = 0;
  htim16.Init.CounterMode = TIM_COUNTERMODE_UP;
  htim16.Init.Period = 4095;
  htim16.Init.ClockDivision = TIM_CLOCKDIVISION_DIV1;
  htim16.Init.RepetitionCounter = 0;
  htim16.Init.AutoReloadPreload = TIM_AUTORELOAD_PRELOAD_ENABLE;
  if (HAL_TIM_Base_Init(&htim16) != HAL_OK)
  {
    Error_Handler();
  }
  if (HAL_TIM_PWM_Init(&htim16) != HAL_OK)
  {
    Error_Handler();
  }
  sConfigOC.OCMode = TIM_OCMODE_PWM1;
  sConfigOC.Pulse = 0;
  sConfigOC.OCPolarity = TIM_OCPOLARITY_LOW;
  sConfigOC.OCNPolarity = TIM_OCNPOLARITY_HIGH;
  sConfigOC.OCFastMode = TIM_OCFAST_DISABLE;
  sConfigOC.OCIdleState = TIM_OCIDLESTATE_RESET;
  sConfigOC.OCNIdleState = TIM_OCNIDLESTATE_RESET;
  if (HAL_TIM_PWM_ConfigChannel(&htim16, &sConfigOC, TIM_CHANNEL_1) != HAL_OK)
  {
    Error_Handler();
  }
  sBreakDeadTimeConfig.OffStateRunMode = TIM_OSSR_DISABLE;
  sBreakDeadTimeConfig.OffStateIDLEMode = TIM_OSSI_DISABLE;
  sBreakDeadTimeConfig.LockLevel = TIM_LOCKLEVEL_OFF;
  sBreakDeadTimeConfig.DeadTime = 0;
  sBreakDeadTimeConfig.BreakState = TIM_BREAK_DISABLE;
  sBreakDeadTimeConfig.BreakPolarity = TIM_BREAKPOLARITY_HIGH;
  sBreakDeadTimeConfig.BreakFilter = 0;
  sBreakDeadTimeConfig.AutomaticOutput = TIM_AUTOMATICOUTPUT_DISABLE;
  if (HAL_TIMEx_ConfigBreakDeadTime(&htim16, &sBreakDeadTimeConfig) != HAL_OK)
  {
    Error_Handler();
  }
  HAL_TIM_MspPostInit(&htim16);

}

void HAL_TIM_PWM_MspInit(TIM_HandleTypeDef* tim_pwmHandle)
{

  if(tim_pwmHandle->Instance==TIM1)
  {
    /* TIM1 clock enable */
    __HAL_RCC_TIM1_CLK_ENABLE();
  }
}

void HAL_TIM_Base_MspInit(TIM_HandleTypeDef* tim_baseHandle)
{

  if(tim_baseHandle->Instance==TIM3)
  {
    /* TIM3 clock enable */
    __HAL_RCC_TIM3_CLK_ENABLE();
  }
  else if(tim_baseHandle->Instance==TIM14)
  {
    /* TIM14 clock enable */
    __HAL_RCC_TIM14_CLK_ENABLE();
  }
  else if(tim_baseHandle->Instance==TIM16)
  {
    /* TIM16 clock enable */
    __HAL_RCC_TIM16_CLK_ENABLE();
  }
}
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

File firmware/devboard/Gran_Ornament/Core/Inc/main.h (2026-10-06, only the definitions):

#define BTN_Pin GPIO_PIN_0
#define BTN_GPIO_Port GPIOA
#define VBAT_SENSE_Pin GPIO_PIN_1
#define VBAT_SENSE_GPIO_Port GPIOA

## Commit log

2026-09-24 Sep 24, 2026, 5:18 PM
    [PCB.kicad_pcb, PCB.kicad_sch]
2026-09-25 Blink via led_on() so the logic is testable
2026-09-25 Stop tracking KiCad local history
2026-09-25 Add GoogleTest host tests and 4-hour AutoOff timer logic
2026-09-28 Add TIM3 PWM output on PA6 and sweep duty in app_run
2026-09-29 TIM3 PWM on PA6: open-drain output, active-low polarity
2026-09-29 Make KiCad libs project-local and move pre-push gate to tools/
    - Add project sym-lib-table/fp-lib-table pointing JLC2KiCad at the
    in-repo library via ${KIPRJMOD}, so a fresh clone opens without
    the author's global KiCad library config
    - Use ${KIPRJMOD}-based paths for the custom 3D models
    - Remove stale nested JLC2KiCad_lib/JLC2KiCad_lib copy
    - Move pre-push.ps1 to tools/ and update the git hook
    [PCB.kicad_pcb]
2026-09-29 Enforce clang-format and clang-tidy via tools/lint.ps1
    .clang-format and .clang-tidy existed but nothing ran them. Add
    tools/lint.ps1 (format check + clang-tidy against the firmware compile
    database with the ARM GCC headers), run it from the pre-push gate and a
    new lint CI job, and scope it to App/ and host test code so CubeMX
    Core/ and Drivers/ stay untouched.
    .clang-tidy gains HeaderFilterRegex: newer clang-tidy reports every
    non-system header by default, which flagged ~1,650 HAL/CMSIS findings.
    Document the checks in firmware/README.md and the CHANGELOG, add
    firmware/tests/ to the README folder table, and fix a garbled
    STM32CubeIDE in the firmware layout table.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
2026-09-29 Led pwm bringup
    Implemented PWM on the available legs
2026-09-30 Led pwm bringup (#4)
    * LED PWM bring-up on devboard, star LEDs share one channel
    * Apply clang-format to app.cpp
    * Extract PWM duty calculation and add host tests
    * Button wake, mode change and Standby on devboard
    * Button wake, mode change and Standby on devboard
    * Fix pre-push gate: MSYS2 g++ failed silently when run from the git hook
    [Gran_Ornament.ioc, app.cpp, power.cpp]
2026-10-01 Fixed GPIO issue, added breathing mode, updated PCB (#5)
    * Fixed GPIO issue, added breathing mode, updated PCB
    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
    [PCB.kicad_sch]
2026-10-01 updated PCB design (#7)
    [PCB.kicad_pcb, PCB.kicad_sch]
2026-10-03 Major update to PCB layout, nearly ready for first batch (#8)
    [PCB.kicad_pcb, PCB.kicad_sch]
2026-10-03 First revision of the board ready (#9)
    [PCB.kicad_pcb, PCB.kicad_sch]
2026-10-05 Rev1 fab settings and small file updates (#10)
    * Small file updates
    * Save Rev1 fabrication plot settings
    [PCB-BOM-JLC.csv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]
2026-10-05 Add LED current sweep results and fix bring-up notes rendering (#11)
    [2026-10-05-led-current-sweep.csv]
2026-10-06 battery measurement (#12)
    * Battery measurement, brightness compensation, low-battery cutoff and fades
    * Bring docs up to date

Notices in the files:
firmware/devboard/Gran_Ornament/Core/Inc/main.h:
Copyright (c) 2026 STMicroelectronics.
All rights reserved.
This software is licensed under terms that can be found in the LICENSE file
